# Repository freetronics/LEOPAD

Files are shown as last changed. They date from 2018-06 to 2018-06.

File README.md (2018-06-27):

Freetronics LeoPad
====================
Copyright 2018 Freetronics Pty Ltd  www.freetronics.com  

A USB keypad with an ATMega32u4 controller, compatible with the Arduino
Leonardo.

Features:

 * ATmega 32u4 MCU
 * 20-key keypad (4x5 matrix)
 * HWB (hardware boot) button and solder jumper to allow disabling bootloader
 * 128x32 OLED module
 * USB-C connector

You can view more details at:

  http://www.freetronics.com.au/leopad

INSTALLATION
------------
The design is saved as an EAGLE project. EAGLE PCB design software is
available from www.cadsoftusa.com free for non-commercial use. To use
this project download it and place the directory containing these files
into the "eagle" directory on your computer. Then open EAGLE and
navigate to the project.

CREDITS
-------
Jonathan Oxer jon@freetronics.com

DISTRIBUTION
------------
The specific terms of distribution of this project are governed by the
license referenced below.

LICENSE
-------
Licensed under the TAPR Open Hardware License (www.tapr.org/OHL).
The "license" folder within this repository also contains a copy of
this license in plain text format.

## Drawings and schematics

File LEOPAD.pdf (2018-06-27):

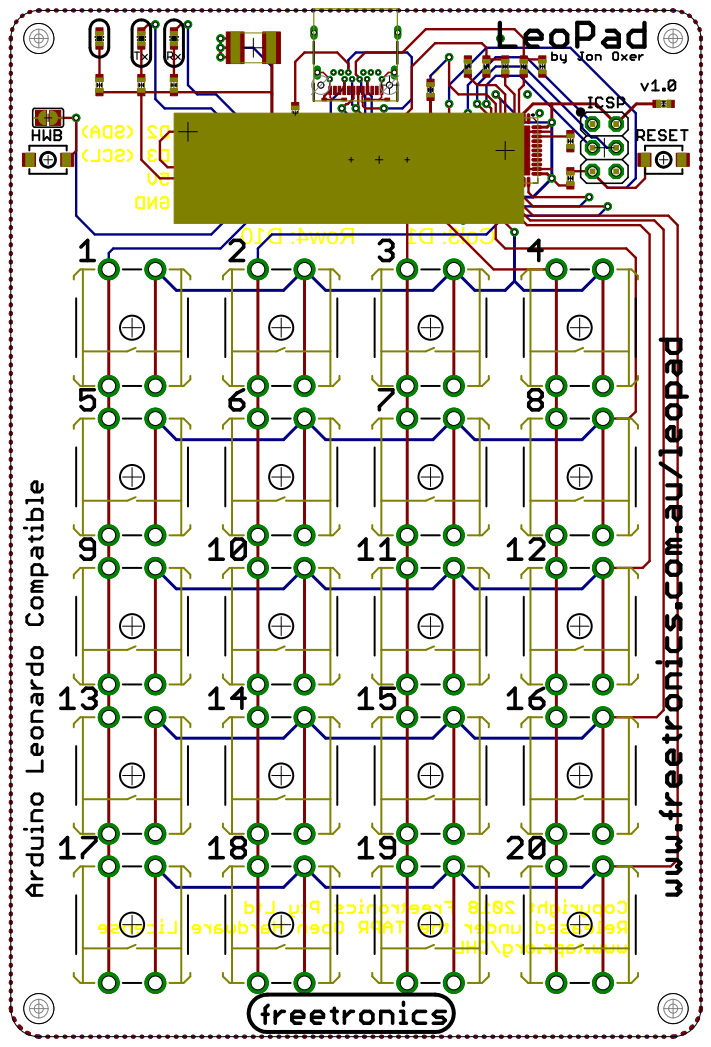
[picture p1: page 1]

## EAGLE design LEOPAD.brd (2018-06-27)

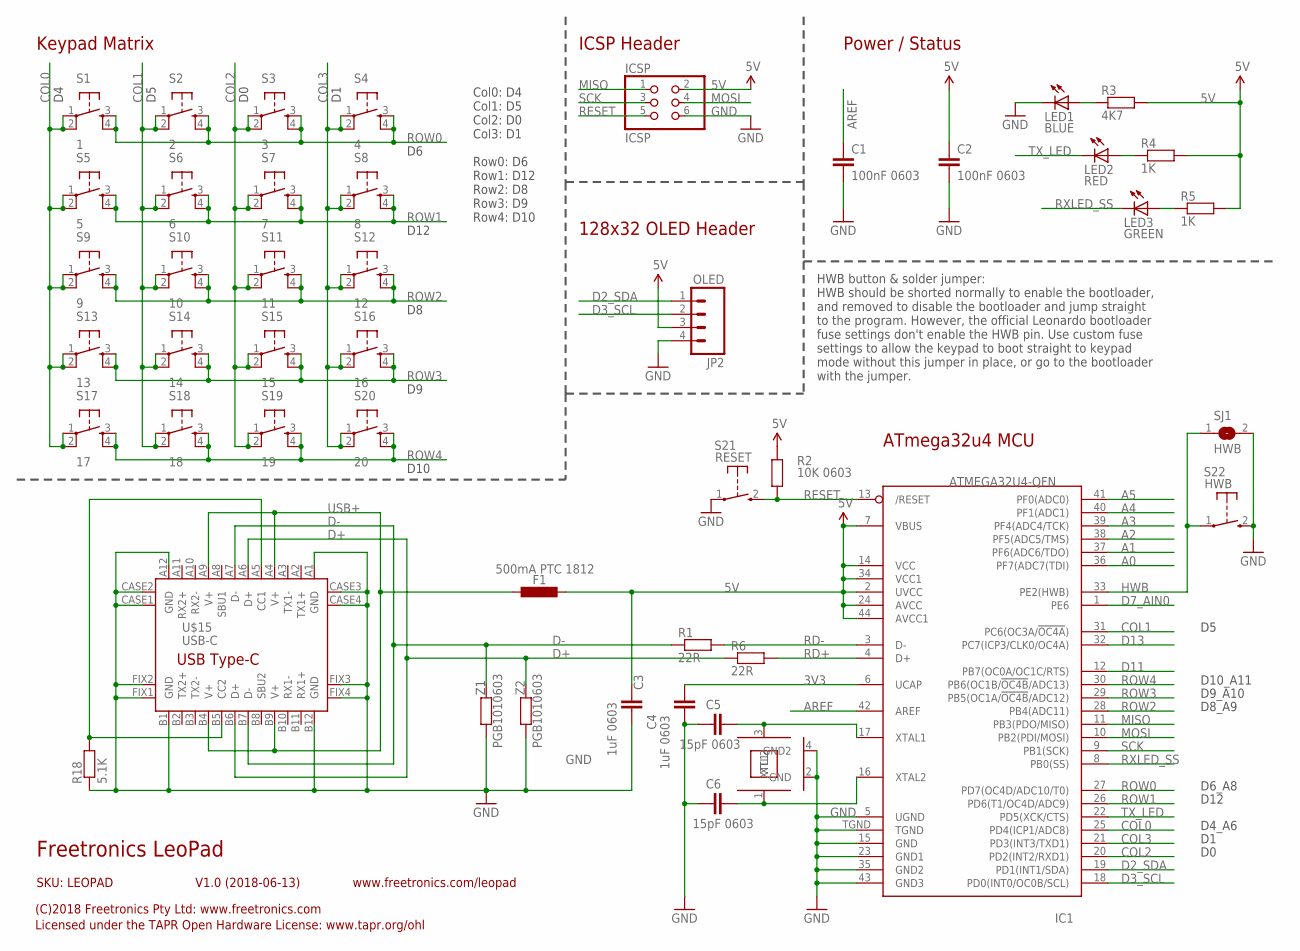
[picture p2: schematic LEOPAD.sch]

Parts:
C1, C2: 100nF 0603; 0603
C3, C4: 1uF 0603; 0603
C5, C6: 15pF 0603; 0603
F1: 500mA PTC 1812; L1812
IC1: ATMEGA32U4-QFN; QFN-44N
ICSP: ICSP; 2X03
JP2: OLED; 1X04
LED1: BLUE; LED-0603
LED2: RED; LED-0603
LED3: GREEN; LED-0603
R1, R6: 22R; 0603
R2: 10K 0603; 0603
R3: 4K7; 0603
R4, R5: 1K; 0603
R18: 5.1K; 0603
S1: 1; TACTILE-PTH-12MM
S2: 2; TACTILE-PTH-12MM
S3: 3; TACTILE-PTH-12MM
S4: 4; TACTILE-PTH-12MM
S5: 5; TACTILE-PTH-12MM
S6: 6; TACTILE-PTH-12MM
S7: 7; TACTILE-PTH-12MM
S8: 8; TACTILE-PTH-12MM
S9: 9; TACTILE-PTH-12MM
S10: 10; TACTILE-PTH-12MM
S11: 11; TACTILE-PTH-12MM
S12: 12; TACTILE-PTH-12MM
S13: 13; TACTILE-PTH-12MM
S14: 14; TACTILE-PTH-12MM
S15: 15; TACTILE-PTH-12MM
S16: 16; TACTILE-PTH-12MM
S17: 17; TACTILE-PTH-12MM
S18: 18; TACTILE-PTH-12MM
S19: 19; TACTILE-PTH-12MM
S20: 20; TACTILE-PTH-12MM
S21: RESET; TACTILE_SWITCH_SMD_2PIN_TINY
S22: HWB; TACTILE_SWITCH_SMD_2PIN_TINY
SJ1: HWB; SJ
U$15: USB-C; USB-C-U52A
XTL1: 16MHz; CRYSTAL-SMD-3X2
Z1, Z2: PGB1010603; 0603

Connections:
3V3: C4.2, IC1.6 (UCAP)
5V: C2.1, C3.1, F1.2, IC1.2 (UVCC), IC1.7 (VBUS), IC1.14 (VCC), IC1.24 (AVCC), IC1.34 (VCC1), IC1.44 (AVCC1), ICSP.2, JP2.3, R2.2, R3.2, R4.2, R5.2
A0: IC1.36 (PF7(ADC7(TDI))
A1: IC1.37 (PF6(ADC6/TDO))
A2: IC1.38 (PF5(ADC5/TMS))
A3: IC1.39 (PF4(ADC4/TCK))
A4: IC1.40 (PF1(ADC1))
A5: IC1.41 (PF0(ADC0))
AREF: C1.1, IC1.42 (AREF)
COL0: IC1.25 (PD4(ICP1/ADC8)), S1.1, S1.2, S5.1, S5.2, S9.1, S9.2, S13.1, S13.2, S17.1, S17.2
COL1: IC1.31 (PC6(OC3A/!OC4A!)), S2.1, S2.2, S6.1, S6.2, S10.1, S10.2, S14.1, S14.2, S18.1, S18.2
COL2: IC1.20 (PD2(INT2/RXD1)), S3.1, S3.2, S7.1, S7.2, S11.1, S11.2, S15.1, S15.2, S19.1, S19.2
COL3: IC1.21 (PD3(INT3/TXD1)), S4.1, S4.2, S8.1, S8.2, S12.1, S12.2, S16.1, S16.2, S20.1, S20.2
D2_SDA: IC1.19 (PD1(INT1/SDA)), JP2.1
D3_SCL: IC1.18 (PD0(INT0/OC0B/SCL)), JP2.2
D7_AIN0: IC1.1 (PE6)
D11: IC1.12 (PB7(OC0A/OC1C/RTS))
D13: IC1.32 (PC7(ICP3/CLK0/OC4A))
D+: R6.1, U$15.A6 (D+), U$15.B6 (D+), Z2.2
D-: R1.1, U$15.A7 (D-), U$15.B7 (D-), Z1.2
GND: C1.2, C2.2, C3.2, C4.1, C5.1, C6.1, IC1.5 (UGND), IC1.15 (GND), IC1.23 (GND1), IC1.35 (GND2), IC1.43 (GND3), IC1.TGND, ICSP.6, JP2.4, LED1.C, R18.1, S21.1, S22.2 (S), SJ1.2, U$15.A1 (GND), U$15.A12 (GND), U$15.B1 (GND), U$15.B12 (GND), U$15.CASE1 (GND), U$15.CASE2 (GND), U$15.CASE3 (GND), U$15.CASE4 (GND), U$15.FIX1 (GND), U$15.FIX2 (GND), U$15.FIX3 (GND), U$15.FIX4 (GND), XTL1.2 (GND), XTL1.4 (GND2), Z1.1, Z2.1
HWB: IC1.33 (PE2(HWB)), S22.1, SJ1.1
MISO: IC1.11 (PB3(PDO/MISO)), ICSP.1
MOSI: IC1.10 (PB2(PDI/MOSI)), ICSP.4
unnamed: LED1.A, R3.1
unnamed: LED2.A, R4.1
unnamed: LED3.A, R5.1
unnamed: C5.2, IC1.17 (XTAL1), XTL1.3 (XTL2)
unnamed: C6.2, IC1.16 (XTAL2), XTL1.1 (XTL1)
unnamed: R18.2, U$15.A5 (CC1), U$15.B5 (CC2)
RD+: IC1.4 (D+), R6.2
RD-: IC1.3 (D-), R1.2
RESET: IC1.13 (/RESET), ICSP.5, R2.1, S21.2 (S)
ROW0: IC1.27 (PD7(OC4D/ADC10/T0)), S1.3, S1.4, S2.3, S2.4, S3.3, S3.4, S4.3, S4.4
ROW1: IC1.26 (PD6(T1/OC4D/ADC9)), S5.3, S5.4, S6.3, S6.4, S7.3, S7.4, S8.3, S8.4
ROW2: IC1.28 (PB4(ADC11)), S9.3, S9.4, S10.3, S10.4, S11.3, S11.4, S12.3, S12.4
ROW3: IC1.29 (PB5(OC1A/!OC4B!/ADC12)), S13.3, S13.4, S14.3, S14.4, S15.3, S15.4, S16.3, S16.4
ROW4: IC1.30 (PB6(OC1B/!OC4B!/ADC13)), S17.3, S17.4, S18.3, S18.4, S19.3, S19.4, S20.3, S20.4
RXLED_SS: IC1.8 (PB0(SS)), LED3.C
SCK: IC1.9 (PB1(SCK)), ICSP.3
TX_LED: IC1.22 (PD5(XCK/CTS)), LED2.C
USB+: F1.1, U$15.A4 (V+), U$15.A9 (V+), U$15.B4 (V+), U$15.B9 (V+)

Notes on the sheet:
ICSP Header
ATmega32u4 MCU
HWB button & solder jumper: HWB should be shorted normally to enable the bootloader, and removed to disable the bootloader and jump straight to the program. However, the official Leonardo bootloader fuse settings don't enable the HWB pin. Use custom fuse settings to allow the keypad to boot straigh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
Freetronics LeoPad
V1.0 (2018-06-13)
SKU: LEOPAD
(C)2018 Freetronics Pty Ltd: www.freetronics.com
Licensed under the TAPR Open Hardware License: www.tapr.org/ohl
www.freetronics.com/leopad
Power / Status
D10_A11
D9_A10
D8_A9
D6_A8
D12
Col0: D4 Col1: D5 Col2: D0 Col3: D1 Row0: D6 Row1: D12 Row2: D8 Row3: D9 Row4: D10
Keypad Matrix
D4_A6
128x32 OLED Header
D10

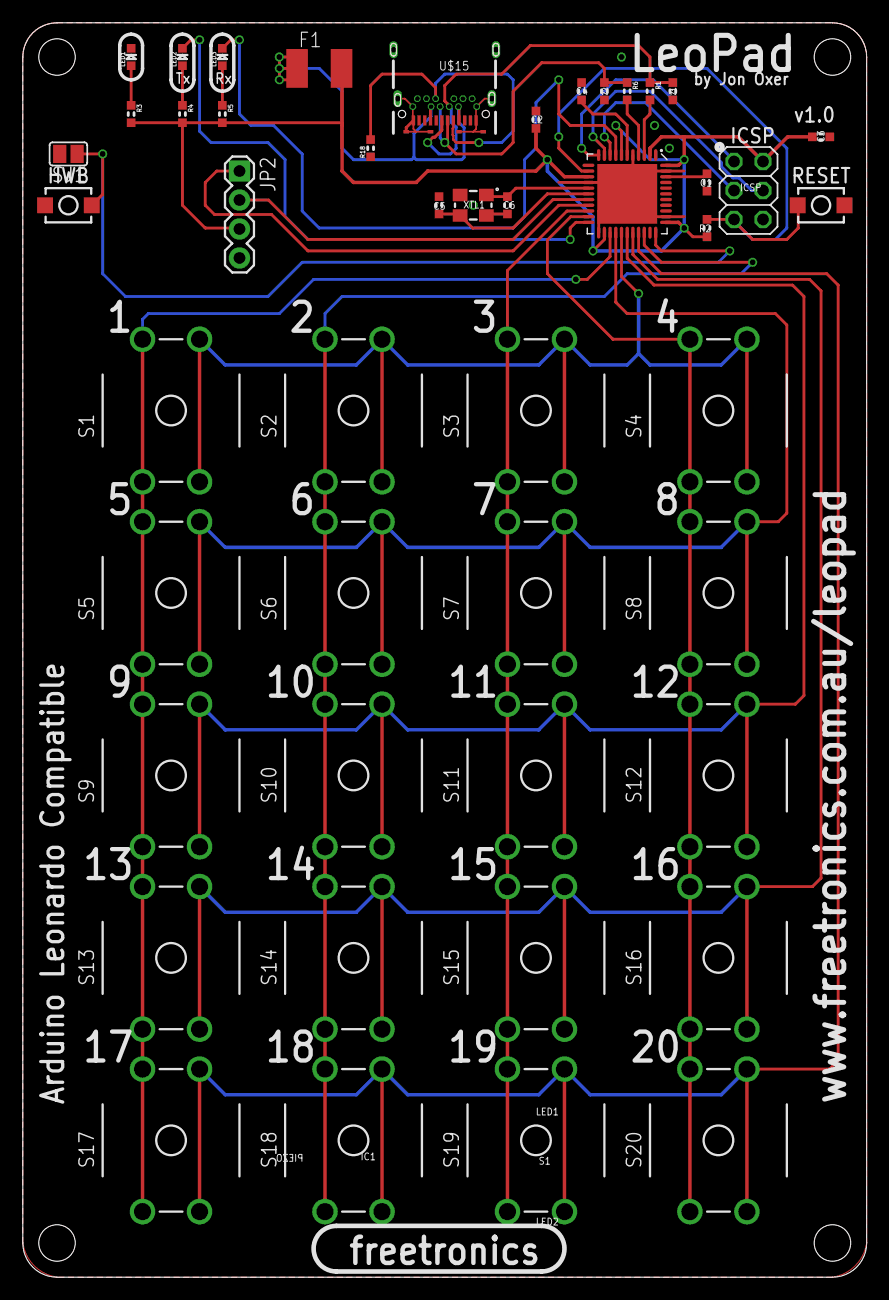
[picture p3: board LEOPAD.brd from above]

Board: 2 copper layers, 74.0 x 110.0 mm, 47 parts (0 on the bottom side), 33 nets.

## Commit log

2018-06-06 Moved over files from LeoStick project
    [LEOPAD.brd, LEOPAD.sch]
2018-06-27 Rework of project into keypad format
    [LEOPAD.brd, LEOPAD.sch]
2018-06-27 Final tweaks for v1.0 release
    [LEOPAD.brd, LEOPAD.sch]

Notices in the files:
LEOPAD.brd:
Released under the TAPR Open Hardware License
